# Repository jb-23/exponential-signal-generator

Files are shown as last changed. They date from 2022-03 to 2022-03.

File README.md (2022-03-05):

# Exponential Step Signal Generator

This circuit generates a fixed waveform of exponentially rising DC steps, which
could be used for testing logarithmic amplifiers.

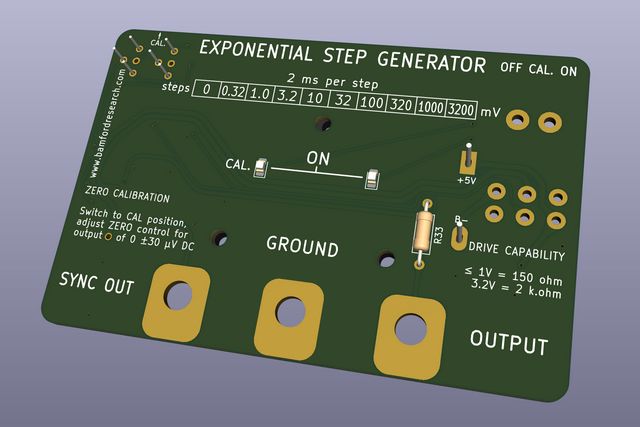
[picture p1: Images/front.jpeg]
Printed circuit board


Output voltages range from 320 uV to 3.2V in steps with a ratio of 3.16,
equivalent to a 10 dB change. The waveform repeats at a nominal 50 Hz to allow
a flicker-free image on an analogue oscilloscope.

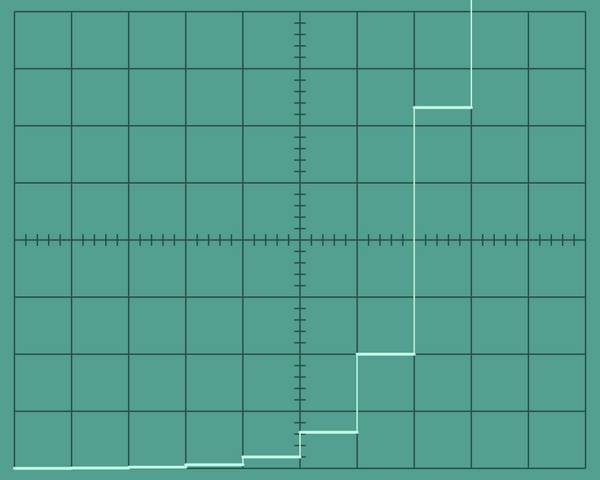
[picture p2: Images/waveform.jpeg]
Waveform rising in exponential steps


The PCB is designed to work as a naked board that sits on top of the 9V battery
that powers it. The output pads are designed to accept the majority of 4mm
binding posts and when unpopulated will also work with crocodile clips.

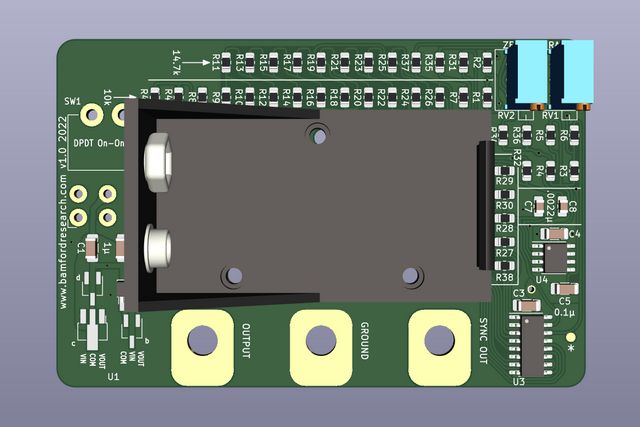
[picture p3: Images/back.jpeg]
Electronic components


The circuit has been laid out primarily in surface mount components; as a
concession to the robustness requirements of the designer, through hole
components are used for the trimmer resistors and the power switch. Further the
trimmer resistor positions will accept components with either staggered or
in-line legs, the former being preferred for mechanical stability.

Multiple footprints for the voltage regulator are provided as a convenience
to accomodate the limited availability of less common negative 5V LDO regulators
required by this design; only one of the options should be fitted.

Resistor R33 can be either a surface mount or through hole component as
is convenient, any value in the range 100 - 150 ohms being adequate if the
preferred value is not available. Higher values will decrease the output drive
capability for the highest voltage steps.

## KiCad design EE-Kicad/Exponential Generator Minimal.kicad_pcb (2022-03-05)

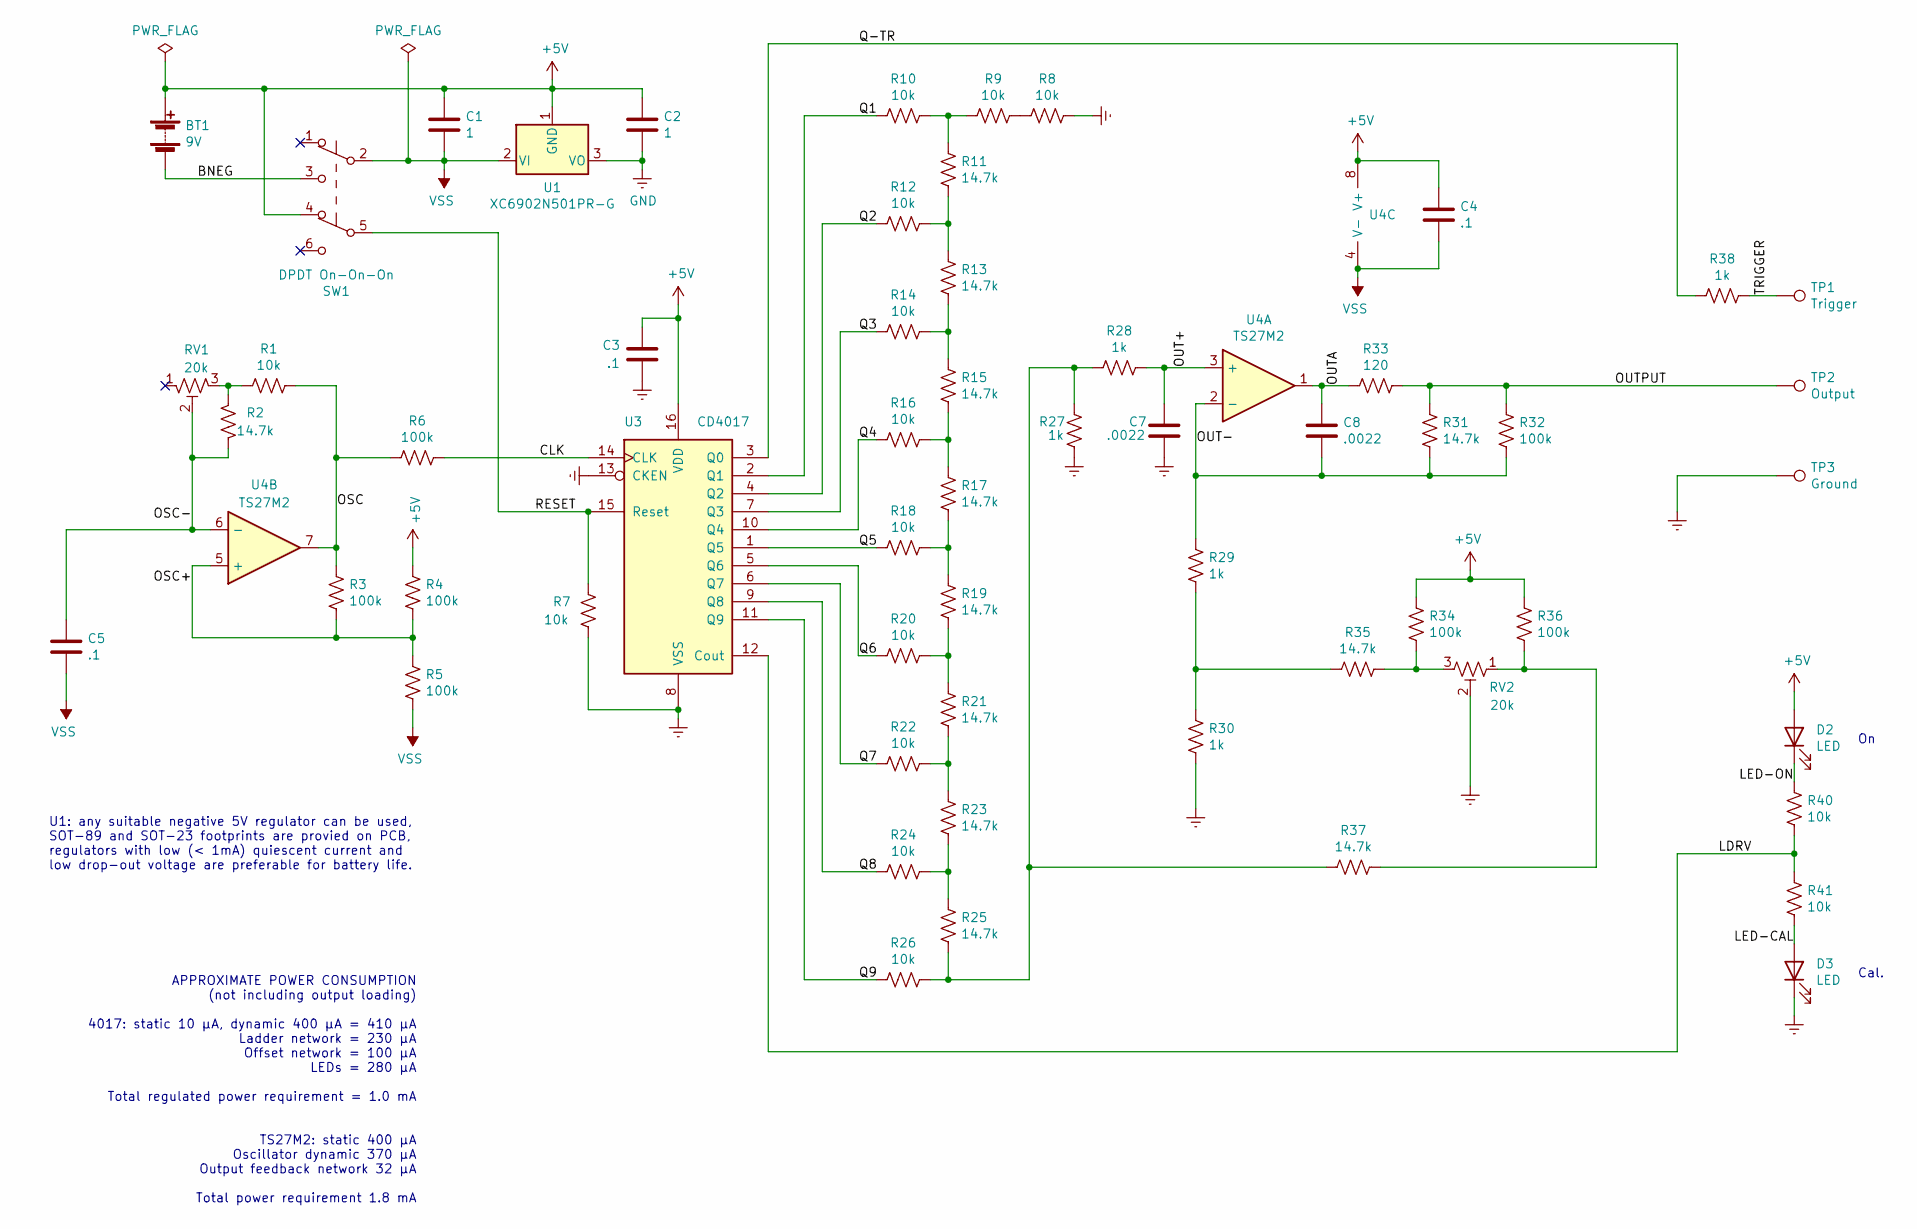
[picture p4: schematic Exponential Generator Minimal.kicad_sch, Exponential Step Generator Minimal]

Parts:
BT1: 9V; BatteryHolder_PCB_PP3
C1, C2: 1; C_1206_3216Metric_Pad1.33x1.80mm_HandSolder
C3, C4, C5: .1; C_1206_3216Metric_Pad1.33x1.80mm_HandSolder
C7, C8: .0022; C_0805_2012Metric_Pad1.18x1.45mm_HandSolder
D2, D3: LED; LED_0805_2012Metric_Pad1.15x1.40mm_HandSolder
R1, R7, R8, R9, R10, R12, R14, R16, R18, R20, R22, R24, R26, R40, R41: 10k; R_0805_2012Metric_Pad1.20x1.40mm_HandSolder
R2, R11, R13, R15, R17, R19, R21, R23, R25, R31, R35, R37: 14.7k; R_0805_2012Metric_Pad1.20x1.40mm_HandSolder
R3, R4, R5, R6, R32, R34, R36: 100k; R_0805_2012Metric_Pad1.20x1.40mm_HandSolder
R27, R28, R29, R30, R38: 1k; R_0805_2012Metric_Pad1.20x1.40mm_HandSolder
R33: 120; R_Axial_DIN0207_L6.3mm_D2.5mm_P10.16mm_Horizontal
RV1, RV2: 20k; Trimmer_Universal_3296_Horizontal
SW1: DPDT On-On-On; Switch_Toggle_DPDT_RA_PCB
TP1: Trigger; Binding_Post
TP2: Output; Binding_Post
TP3: Ground; Binding_Post
U1: XC6902N501PR-G; SOT-89-3_Handsoldering
U3: CD4017; SOIC-16_3.9x9.9mm_P1.27mm
U4: TS27M2; SOIC-8_3.9x4.9mm_P1.27mm

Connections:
+5V: BT1.1 (+), C1.1, C2.1, C3.1, C4.1, D2.2 (A), R4.1, R34.1, R36.1, SW1.4 (A), U1.1 (GND), U3.16 (VDD), U4.8 (V+)
/BNEG: BT1.2 (-), SW1.3 (C)
/CLK: R6.1, U3.14 (CLK)
/LDRV: R40.2, R41.1, U3.12 (Cout)
/LED-CAL: D3.2 (A), R41.2
/LED-ON: D2.1 (K), R40.1
/OSC: R1.1, R3.1, R6.2, U4.7
/OSC+: R3.2, R4.2, R5.1, U4.5 (+)
/OSC-: C5.1, R2.2, RV1.2, U4.6 (-)
/OUT+: C7.1, R28.1, U4.3 (+)
/OUT-: C8.2, R29.1, R31.2, R32.2, U4.2 (-)
/OUTA: C8.1, R33.2, U4.1; also elsewhere on the board
/OUTPUT: R31.1, R32.1, R33.1, TP2.1; also elsewhere on the board
/Q1: R10.2, U3.2 (Q1)
/Q2: R12.2, U3.4 (Q2)
/Q3: R14.2, U3.7 (Q3)
/Q4: R16.2, U3.10 (Q4)
/Q5: R18.2, U3.1 (Q5)
/Q6: R20.2, U3.5 (Q6)
/Q7: R22.2, U3.6 (Q7)
/Q8: R24.2, U3.9 (Q8)
/Q9: R26.2, U3.11 (Q9)
/Q-TR: R38.2, U3.3 (Q0)
/RESET: R7.1, SW1.5 (B), U3.15 (Reset)
/TRIGGER: R38.1, TP1.1
GND: C2.2, C3.2, C7.2, D3.1 (K), R7.2, R8.1, R27.2, R30.2, RV2.2, TP3.1, U1.3 (VO), U3.8 (VSS), U3.13 (CKEN)
unnamed: R1.2, R2.1, RV1.3
unnamed: R8.2, R9.1
unnamed: R9.2, R10.1, R11.1
unnamed: R11.2, R12.1, R13.1
unnamed: R13.2, R14.1, R15.1
unnamed: R15.2, R16.1, R17.1
unnamed: R17.2, R18.1, R19.1
unnamed: R19.2, R20.1, R21.1
unnamed: R21.2, R22.1, R23.1
unnamed: R23.2, R24.1, R25.1
unnamed: R25.2, R26.1, R27.1, R28.2, R37.2
unnamed: R29.2, R30.1, R35.2
unnamed: R34.2, R35.1, RV2.3
unnamed: R36.2, R37.1, RV2.1
VSS: C1.2, C4.2, C5.2, R5.2, SW1.2 (B), U1.2 (VI), U4.4 (V-)

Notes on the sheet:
Cal.
APPROXIMATE POWER CONSUMPTION (not including output loading) 4017: static 10 µA, dynamic 400 µA = 410 µA Ladder network = 230 µA Offset network = 100 µA LEDs = 280 µA Total regulated power requirement = 1.0 mA TS27M2: static 400 µA Oscillator dynamic 370 µA Output feedback network 32 µA Total power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
U1: any suitable negative 5V regulator can be used, SOT-89 and SOT-23 footprints are provied on PCB, regulators with low (< 1mA) quiescent current and low drop-out voltage are preferable for battery life.

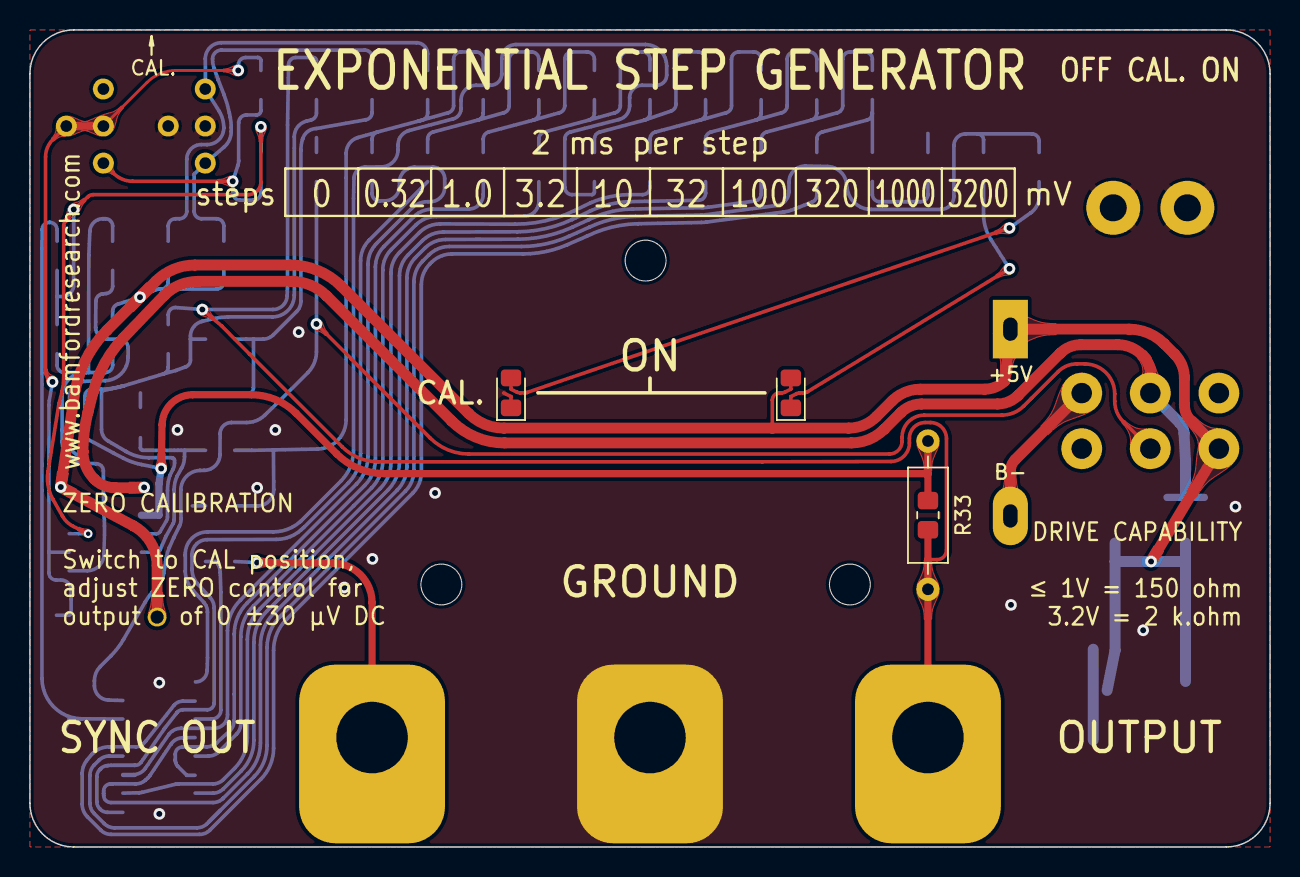
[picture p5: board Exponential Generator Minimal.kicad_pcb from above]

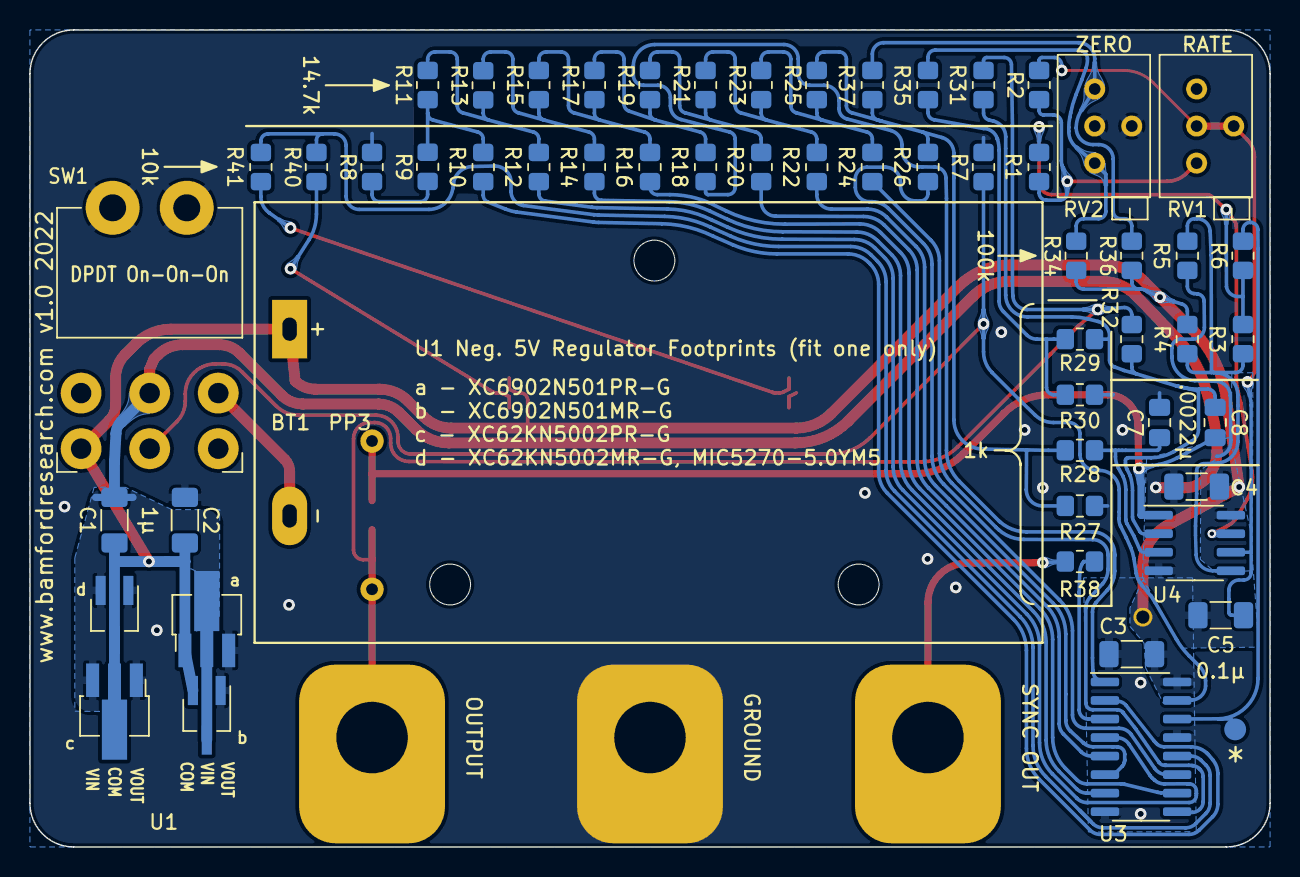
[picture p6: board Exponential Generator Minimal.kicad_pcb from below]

Board: 2 copper layers, 85.0 x 56.0 mm, 60 parts (53 on the bottom side), 41 nets.

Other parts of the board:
R33#2: 120; R_0805_2012Metric_Pad1.20x1.40mm_HandSolder

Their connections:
/OUTA: R33#2.2; also elsewhere on the board
/OUTPUT: R33#2.1; also elsewhere on the board
